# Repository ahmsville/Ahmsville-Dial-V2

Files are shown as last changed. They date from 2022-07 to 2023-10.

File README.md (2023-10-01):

# This Repository contains everything you need to build or customize your very own Ahmsville Dial.

## BUILD INSTRUCTIONS
 - https://www.ahmsvillelabs.io/ahmsvilledialbuild

# Ahmsville-Dial-V2
Main arduino library for the Ahmsville Dial V2.

Other Required Arduino Libraries:

Magnetic Rotary Encoder - https://github.com/ahmsville/Magnetic_rotary_encoding

Capacitive touch - https://github.com/PaulStoffregen/CapacitiveSensor

FastLED - https://github.com/FastLED/FastLED

RF24 - https://github.com/nRF24/RF24

Companion App - https://github.com/ahmsville/Ahmsville-Dial-App

**3D Printing Files** - https://gum.co/bkgfu

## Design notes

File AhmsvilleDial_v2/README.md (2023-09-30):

# Ahmsville-Dial-V2
Main arduino library for the Ahmsville Dial V2.

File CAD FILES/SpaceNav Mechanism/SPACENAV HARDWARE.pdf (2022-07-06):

Part name | Description | Option to Buy | Required Qty Link
10x5x1 magnets | Block Neodymium Magnet | 10x5x1mm | 4 | link (https://www.aliexpress.com/item/1005001409808794.html)
extension spring D3,L10,WT0.3 | 304 Stainless Dual Hook Small Expansion Tension Spring Hardware Accessories Wire Diameter 0.3mm Outer Diameter 3mm | 0.3 x 3 x 10mm | 4 | link (https://www.aliexpress.com/item/1005003468116909.html?scm_id=1007.40050.281175.0&scm-url=1007.40050.281175.0)
compression spring D14,L10,WT1.2 | Compression Spring 304 Stainless Steel Non-corrosive Tension Spring Wire Dia 1.2mm Outer Dia 14mm | 10mm length | 1 | link (https://www.aliexpress.com/item/1005003770155583.html)
Brass rivet M2X5mm HT1.2 | Brass Solid Rivets GB109 M2*L Flat Head Copper Rivets Solid Brass Rivet 2mm Diameter | M2 x 5mm | 4 | link (https://www.aliexpress.com/item/32971512695.html?spm=a2g0s.9042311.0.0.27424c4d3lAx2T)
M1.4 x 6mm Self tapping Screw | | M1.4x6mm | 8 | link (https://www.aliexpress.com/item/4000982209705.html?scm_id=1007.14452.226710.0&scm-url=1007.14452.226710.0)
M1.4 x 4mm Self tapping Screw | | M1.4x4mm | 4 | link (https://www.aliexpress.com/item/4000982209705.html?scm_id=1007.14452.226710.0&scm-url=1007.14452.226710.0)

## SPACENAV HARDWARE

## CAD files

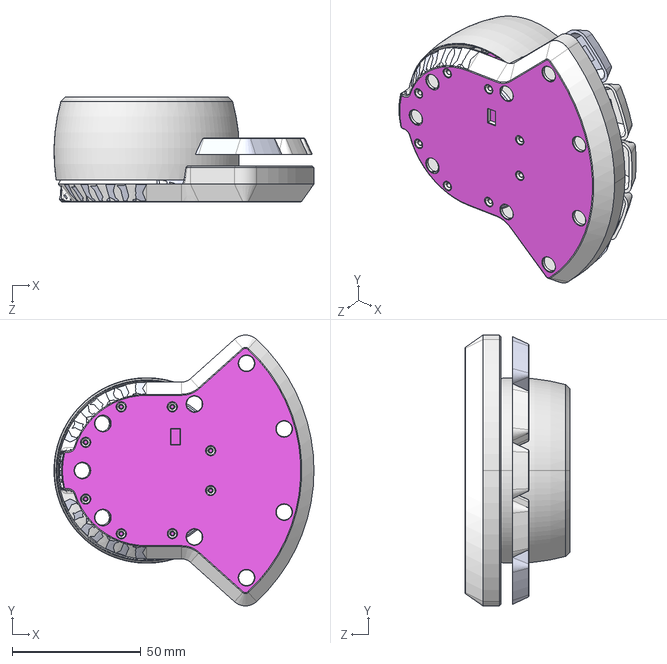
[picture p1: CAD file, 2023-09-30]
CAD FILES/DIAL/Ahmsville Dial - Base and Macro key Edition REV3.STEP
101.1 x 105.4 x 40.9 mm

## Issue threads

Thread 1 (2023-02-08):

Issue with 3D files

marekvse, 2023-02-08:
Hi Ahmed,
I have bought the full kit for Absolute variant from you, wanting to print my own colors. I first printed the case for the USB receiver, but it is obviously wrong. I have purchased the 3D files several weeks before purchasing the kit so the latest 3D files may have changed, but I don't want to purchase the same thing again just to find out if there is another version of the receiver case. In the version of 3D files I have there is v 1 and v1.1 of these.
Is there a newer version? Could you send it to me please? Just for the receiver would be enough, unless something else changed, too.

And I have an additional question if you don't mind...

In the purchased 3D files there are gcode files to print the multi-color parts, but they are (I think obviously, though I'm not a 3D printing expert), not going to work for all 3D printers. I have Creality Ender 3 S1 Plus, which seems to be using a different flavour of GCode.  Would you have some instructions on how to prepare the gcode files from your STLs that are separate for the logo and the rest of the top button for example?

Thanks,
Marek

ahmsville, 2023-02-08:
Hi marek,

Please note that the 3d files are free to download as many times as you like, gumroad only gives you the option to donate to the creator, all you need to do is enter 0 as the price and you can download the latest versions of the 3d files.

the included gcode files are outdated now so only use them as a reference on how to achieve the 2 color print.

marekvse, 2023-02-08:
I see. Thanks for that! :) I downloaded the USB receiver files and sure enough the 1.2 version looks like that should fit the rest I have from you :).

Thank you for a very nice design, too. I have not put it together yet as I'm currently printing the parts, but it does look very well designed. I'm looking forward to experiencing it operate.

I still have no idea how to make any slicer to go over the 3 layers of the logo to avoid them when printing the rest of the knob. I only had partial success in printing it. It's got some holes where the logo parts were pushed out of position. If I printed just the first layer of the logo it would be fine, but would it be strong enough...?

ahmsville, 2023-02-09:
you need at least two layers for the Surface, I could slice the parts for you if you'll like, I use a sapphire plus direct drive 0.6mm nozzle printer, not too far from what you have, so if you can tell me some settings specific to your printer, I can generate a useable gcode for you.

marekvse, 2023-02-09:
That would be great!! :)
I have prepared 1 and 2 layer logo files to try after everything else is printed, but my problem is that I can't seem to be able to make the printing head go up between the places where it prints to not bump into the others. Also, without that and 3 layers the height sensor (BLTouch) is already bumping into the printed layers as well, even though it was still able (just) to stumble over them.
So if you have a facility that makes the Z jumps possible or have some other clever technique I'd be very very happy if you could prepare the gcode for me. Much appreciated!

So, I'm not sure what you may need for the specific settings exactly, but here is what I assume you may need. If anything is missing please let me know:

**Printer settings:**
width: 300mm
depth: 300mm
rectangular
G-code flavor: Marlin

**Printhead settings:**
X min: -26mm
Y min: -32mm
X max: 32 mm
Y max: 34mm
Gantry height: 25mm
Apply extruder offsets to GCode: Yes

I have 0.4mm nozzle on it.

**Start G-code:**
```
; Ender 3 S1 Start G-code
G92 E0 ; Reset Extruder
G28 ; Home all axes
G1 Z10.0 F3000 ; Move Z Axis up little to prevent scratching of Heat Bed
G1 X0 Y0

M104 S{material_print_temperature_layer_0}
M190 S{material_bed_temperature_layer_0}
M109 S{material_print_temperature_layer_0}

G1 X0.1 Y20 Z0.3 F5000.0 ; Move to start position
G1 X0.1 Y200.0 Z0.3 F1500.0 E15 ; Draw the first line
G1 X0.4 Y200.0 Z0.3 F5000.0 ; Move to side a little
G1 X0.4 Y20 Z0.3 F1500.0 E30 ; Draw the second line
G92 E0 ; Reset Extruder
G1 Z2.0 F3000 ; Move Z Axis up little to prevent scratching of Heat Bed
G1 X5 Y20 Z0.3 F5000.0 ; Move over to prevent blob squish
```

**End G-code:**
```
G91 ;Relative positioning
G1 E-2 F2700 ;Retract a bit
G1 E-2 Z0.2 F2400 ;Retract and raise Z
G1 X5 Y5 F3000 ;Wipe out
G1 Z10 ;Raise Z more
G90 ;Absolute positioning

G1 X0 Y{machine_depth} ;Present print
M106 S0 ;Turn-off fan
M104 S0 ;Turn-off hotend
M140 S0 ;Turn-off bed

M84 X Y E ;Disable all steppers but Z
```

ahmsville, 2023-02-09:
the logo printing is done with Z hop, see the gcodes attached, print knob 1_1 first (logo), then print knob 1_2 after (knob), you can also preview the files before printing.
[KNOB 1 GCODE.zip](https://github.com/ahmsville/Ahmsville-Dial-V2/files/10691714/KNOB.1.GCODE.zip)

marekvse, 2023-02-09:
Excellent, thank you so very much.

RE Z hop: Yes, I discovered that when looking for a solution, but it did not seem to work. Maybe the printer does not recognize that G-code...? I'll sure find out when I try the one from you.

marekvse, 2023-02-09:
Which MECH HOLDER should one use: KEYLESS or the keyed one? The last piece to print (except reprinting of KNOB 1.)

By the way, how do you make the keycaps fit?
For others if that helps, I first tried a fine cutting instrument for a little bit before I tried directed hot air (using a soldering station) to heat the cross up a bit and then pressed it into the switch. It becomes a bit lose for a while but when it cools down again the fit is almost perfect (could be a tiny bit tighter, but its perfectly fine it seems, at least for something like this; I'm not sure I'd use this technique for a full keyboard, but maybe even that would work).

ahmsville, 2023-02-09:
I don't have to do any post processing with the keys, the secret is to use the avoid traveling through holes settings, also print at the lower temperature range of the filament, you are also printing the keyed spacenav holder.

marekvse, 2023-02-12:
I see.

Good o know if I want to change the color of the keys and thus print them again :).

Just to let you know that the G-code you made for me, unfortunately, did not work due to two problems. First, when it printed the logo it parked itself and did not finish the printing so that I could not select the second file to print. The second problem was something I should have let you know before, which is that my printer uses the BLTouch sensor at the beginning of every print and so I was doing my tries after I offset the printing position of the two files by 80mm on both x and y axis so that the center stays free for the BLTouch sensor step. Oh, actually the third problem was that it was (I think) printing the skirt and the retracted BLTouch tip was struggling to get across the already printed parts.

So in the end I tried by myself again, trying to print just 2 layers of the logo. That kind of worked, except that it dislodged in two of the four incomplete rings (I'm obviously printing the older design of the logo - just because I already had the gcode ready for it) and I then kind of fixed that with a 3D printing pen, filling manually the resulting inside ridges and thus also re-fixing the top to be all connected.
Thank you for the gcode files nevertheless!

Now I have two (probably last) questions if I may:

1) Will the capacitive touch work even after I made the inside top of the top knob slightly uneven after working with the hand-held 3D pen inside there? Is it designed so that it aligns perfectly with the inside top or is there a bit of space between the plastic and the capacitive sensor?

2) Does the dial work without having the battery installed?
  (I thought I don't need the wireless connection so I did not order the battery originally and it was only now that I realized that there is a possibility that the device will actually not work without it... So will it or will it not?)

Thanks,

Marek

ahmsville, 2023-02-14:
Hi Merek,

The capacitive touch will work regardless of the top surface's smoothness, the dial will also work without a lipo battery, to bypass the lipo charging circuit you can desolder the x4 pads and connect the pads beside it, doing this will provide the dial with stable power in the absence of a lipo. see attached picture.
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

marekvse, 2023-02-15:
Excellent. Thank you Ahmed for all your support. I still have not had the time yet to finish assembling the device but I can't wait to see it working.

ahmsville, 2023-02-15:
I am happy to help.

marekvse, 2023-03-11:
Hello Ahmed, sorry to bother you again. I have just finally found time to put all the magnets in and finish the assembly. In the meantime, the battery actually arrived so I connected the battery and thus powered the device for the first time. It seems to be running, the lights work, the capacitative touch works for Pause / Play youtube videos, but the thing I was most excited about to use it for of course was Fusion 360. I've followed the complete installation procedure and pressing the 5th button shows the popup identifying Fusion 360 correctly:
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
However, I'm getting no response whatsoever in Fusion from the dial so I cannot be sure that the dial actually works apart from the 5th button and the capacitative touch.
I have also confirmed that the Ahmsville Fusion 360 addin is installed and running in Fusion 360.

One thing I have not done yet is to push the knobs onto the bearings as it looks like it would be very hard, if not impossible, to get them off again after that and until I confirm that it all works I don't want to prevent myself from accessing the wiring.

Could you provide any guidance?

marekvse, 2023-03-14:
Finally, I want to say thank you! :) I've finally managed to find the time to put all the magnets in, in the meantime, even the battery arrived and yesterday I finally managed to connect the device for the first time. Above, now hidden comment, I first wrote for help as only the capacitive touch seemed to work and no functions in Fusion 360, but then it finally, somehow, managed to start working. I found that I need a longer cable to use the device where I need it and I need to finish building my smaller keyboard to fit it all to the space I have, but the important thing is here that it works.

One question in the end... If I even need to disassemble it, have you tested whether the knobs can be taken off the bearings safely without breaking anything. I'd be worried if I ever needed to do that.

Oh, actually one more comment: The bottom knob rotates reasonably freely - that is if I give it a faster push it keeps rotating for about a second after the force ends (I expected better, but nevertheless it is very easy to rotate), but the top one has more resistance and cannot be easily rotated with just one finger without tilting the device. Is that by design to have to rotate it with a two-finger grip?

Closed 2023-02-08.

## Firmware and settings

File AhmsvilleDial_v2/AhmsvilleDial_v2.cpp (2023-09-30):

#include "AhmsvilleDial_v2.h"



/*


....By Ahmed Oyenuga (Ahmsville 2019).
*/


//MagRotaryEncoder AhmsvilleDial_Knob = MagRotaryEncoder(A1, A0, 38, 27); // create new encoding instance and specify the arduino pins connected to the hall effect sensors
MagRotaryEncoder AhmsvilleDial_Knob = MagRotaryEncoder(A1, A0);
#if DIAL_VERSION == 3 || DIAL_VERSION == 4
//MagRotaryEncoder AhmsvilleDial_Knob2 = MagRotaryEncoder(A2, A3, 42, 13);
MagRotaryEncoder AhmsvilleDial_Knob2 = MagRotaryEncoder(A2, A3);

#endif


volatile int activesensorInterrupt = 1, knob2activesensorInterrupt = 1;


void mainISR1() {

	AhmsvilleDial_Knob.singleSensor_INT(1);
}
#if DIAL_VERSION == 3 || DIAL_VERSION == 4
void mainISR2() {

	AhmsvilleDial_Knob2.singleSensor_INT(1);
}

#endif
void setknobinterrupt() {
	pinMode(AhmsvilleDial_Knob.get_sensorINTpin(1), INPUT);
	attachInterrupt(digitalPinToInterrupt(AhmsvilleDial_Knob.get_sensorINTpin(1)), mainISR1, RISING);

	pinMode(AhmsvilleDial_Knob.get_sensorINTpin(2), INPUT);
	attachInterrupt(digitalPinToInterrupt(AhmsvilleDial_Knob.get_sensorINTpin(2)), mainISR1, RISING);

#if DIAL_VERSION == 3 || DIAL_VERSION == 4
	pinMode(AhmsvilleDial_Knob2.get_sensorINTpin(1), INPUT);
	attachInterrupt(digitalPinToInterrupt(AhmsvilleDial_Knob2.get_sensorINTpin(1)), mainISR2, RISING);

	pinMode(AhmsvilleDial_Knob2.get_sensorINTpin(2), INPUT);
	attachInterrupt(digitalPinToInterrupt(AhmsvilleDial_Knob2.get_sensorINTpin(2)), mainISR2, RISING);
#endif // DIAL_VERSION == 3 || DIAL_VERSION == 4


}


AhmsvilleDial::AhmsvilleDial() {
	pinMode(30, OUTPUT);
	digitalWrite(30, LOW);
	delay(500);
}

void AhmsvilleDial::resetdial() {

	//AhmsvilleDial_Touch = AdvCapTouch();
	//AhmsvilleDial_Knob = MagRotaryEncoder(A1, A0, 38, 27);
#if DIAL_VERSION == 3 || DIAL_VERSION == 4
	//AhmsvilleDial_Knob2 = MagRotaryEncoder(A2, A3, 42, 13);
	AhmsvilleDial_Spacenav.softreset();
	if(gyro_x_y_radius[2] > 0.0){
          AhmsvilleDial_Spacenav.set_tiltBoundaryRadii(100, gyro_x_y_radius[2]+0.5);
    }
    if(plane_x_y_radius[2] > 0.0){
        AhmsvilleDial_Spacenav.set_slideBoundaryRadii(100, plane_x_y_radius[2]+0.5);
    }
	/*AhmsvilleDial_Spacenav.set_XYSensorPins(A5, A4);
	AhmsvilleDial_Spacenav.set_adaptiveSpaceNavigation(true);
	AhmsvilleDial_Spacenav.set_slideBoundaryRadii(100, 0);
	AhmsvilleDial_Spacenav.set_tiltBoundaryRadii(100, 0);
	AhmsvilleDial_Spacenav.initialize_spaceNav();*/
#endif // DIAL_VERSION == 3 || DIAL_VERSION == 4

#if DIAL_VERSION == 2 || DIAL_VERSION == 4
	//AhmsvilleDial_Mkey = MacroKey();
#endif // DIAL_VERSION == 2 || DIAL_VERSION == 4

}
void AhmsvilleDial::initialize_ahmsvilleDial() {
	//setknobinterrupt();
	set_haptics(4, 60, 20, 5, 200); //int pin, int durationtouch, int durationknob, int durationspacenav, int strength

	analogReadResolution(12);
	setknobresolution(0, 1,false);


#if DIAL_VERSION == 3 || DIAL_VERSION == 4

	setknobresolution(0,2,false);

	AhmsvilleDial_Spacenav.set_XYSensorPins(A5, A4);
	AhmsvilleDial_Spacenav.set_adaptiveSpaceNavigation(false);
	AhmsvilleDial_Spacenav.set_slideBoundaryRadii(100, 0);
	AhmsvilleDial_Spacenav.set_tiltBoundaryRadii(100, 0);

	AhmsvilleDial_Spacenav.initialize_spaceNav();
#endif // DIAL_VERSION == 3 || DIAL_VERSION == 4

	AhmsvilleDial_Touch.set_capTouchPins(9, 8, 0, 0, 0);   //sets the arduino pins used for the capacitive touch (sendpin, pad1, pad2, pad3, pad4)
	//AhmsvilleDial_Touch.set_inputTypeThresholds(300, 320, 800, 250);  //sets the thresholds for the four input types  (singletap, shortpress, longpress, doubletapspeed)
	//AhmsvilleDial_Touch.set_adaptiveSensitivity(1, 0.4, true);  //set touch sensitivity to auto
	AhmsvilleDial_Touch.initialize_capTouch(1);

#if DIAL_VERSION == 2 || DIAL_VERSION == 4
	AhmsvilleDial_Mkey.initialize_macroKey();
#endif // DIAL_VERSION == 2 || DIAL_VERSION == 4



	Keyboard.begin();
	Mouse.begin();
}

void AhmsvilleDial::initialize_ahmsvilleDialCustom(int touchpin) {

}

void AhmsvilleDial::set_inputTypeThresholds(int st, int sp, int lp, int dt) {
	AhmsvilleDial_Touch.set_inputTypeThresholds(st, sp, lp, dt);
}

void AhmsvilleDial::set_haptics(int pin, int durationtouch, int durationknob, int durationspacenav, int strength) {
	AhmsvilleDial_Touch.set_haptics(pin, durationtouch, 255);
	AhmsvilleDial_Knob.set_haptics(pin, durationknob, strength);
	haptics_pin = pin;

#if DIAL_VERSION == 3 || DIAL_VERSION == 4
	AhmsvilleDial_Knob2.set_haptics(pin, durationknob, 255);
	AhmsvilleDial_Spacenav.set_haptics(pin, durationspacenav, 75);
#endif // DIAL_VERSION == 3 || DIAL_VERSION == 4

}

int AhmsvilleDial::capTouch(int pad) {

	int touch = AhmsvilleDial_Touch.detect_touchFromNoise(pad);
	return touch;


}

void AhmsvilleDial::capTouchInterrupt() {

	AhmsvilleDial_Touch.read_valueFromNoise_interrupt();

}

int AhmsvilleDial::capTouch() {
	int touch = AhmsvilleDial_Touch.detect_touchFromNoise(0);
	return touch;
}

int AhmsvilleDial::capTouch_single() {
	int touch = AhmsvilleDial_Touch.detect_touchFromNoise_single(0);
	return touch;
}

int AhmsvilleDial::capTouch_single(int pad) {
	int touch = AhmsvilleDial_Touch.detect_touchFromNoise_single(pad);
	return touch;
}



int AhmsvilleDial::knob() {
	knobcount = 0;
	if (knob1setres > 0)
	{
		knobcount = int(AhmsvilleDial_Knob.detect_rotationHR());
	}
	else {
		knobcount = AhmsvilleDial_Knob.detect_rotation();
	}
	if (knobcount != 0) {
		AhmsvilleDial_Knob.setsleep(false);
	}
	//SerialUSB.println(knobcount);
	return knobcount;
}

float AhmsvilleDial::knobAbsolute() {
	float knobfloatcount = 0;
	if (knob1setres == 0) {
		knobfloatcount = float(AhmsvilleDial_Knob.detect_rotation());
	}
	else {
		knobfloatcount = AhmsvilleDial_Knob.detect_rotationHR();
	}

	if (knobfloatcount != 0) {
		AhmsvilleDial_Knob.setsleep(false);
	}

	return knobfloatcount;
}


void AhmsvilleDial::normalize() {

	//AhmsvilleDial_Touch.update_basevalueFromNoise(0);
	//AhmsvilleDial_Knob.recaliberate_startPosition();
	eventnotification(0);

#if DIAL_VERSION == 2 || DIAL_VERSION == 4
	//AhmsvilleDial_Mkey.reset_macroKey();
#endif // 0	

#if DIAL_VERSION == 3 || DIAL_VERSION == 4
	//AhmsvilleDial_Knob2.recaliberate_startPosition();

	AhmsvilleDial_Spacenav.reset_spaceNav();
#endif // DIAL_VERSION == 3 || DIAL_VERSION == 4
}
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

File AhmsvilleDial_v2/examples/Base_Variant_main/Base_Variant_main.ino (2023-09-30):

#include <AhmsvilleDial_v2.h>
#include <FastLED.h>
#include <SPI.h>
#include "RF24.h"

#define maxconfignum 1

AhmsvilleDial ahmsville_dial; //create a new ahmsville dial instance
RF24 radio(6, 7);                          // Set up nRF24L01 radio on SPI bus plus pins 7 & 8(CE,CSN)



#define substrlen 12
#define serialdatalength 30



byte addresses[][6] = { "1Node", "2Node" };



#define DATA_PIN    3
#define LED_TYPE    WS2812B
#define COLOR_ORDER GRB
#define NUM_LEDS   8
#define MK_LEDS   0


CRGB leds[NUM_LEDS];

#define BRIGHTNESS         96

CRGBPalette16 currentPalette;
TBlendType    currentBlending;

uint8_t gHue = 0; // rotating "base color"


#define MOUSEMOVE '/'
#define MOUSEMOVE_UP 'U'
#define MOUSEMOVE_DOWN 'D'
#define MOUSEMOVE_LEFT 'L'
#define MOUSEMOVE_RIGHT 'R'
char KEY_SPACEBAR = 32;
char nullchar = 128;

#define ALLColors CRGB::Teal
#define NotSet CRGB::Snow
#define solid 0
#define ColorWheel 1
#define Breath 2
#define Cardio 3
#define Rainbow 4
#define SpacklingRainbow 5
#define Confetti 6
#define Jungle 7


struct {
  uint8_t brightness = BRIGHTNESS;
  uint8_t gHue = 0;
  long gHuetiming = 0;
  long timing = 0;
  uint8_t state = 0;
} Dleds[NUM_LEDS];


struct {
  int beatcount = 0;
  int breathfader = 1;
} A_variables[NUM_LEDS];


int blackpoint = 240;


// the following lines define the index of loaded config to be used in the Dial App
#define knob1CW "the app is in charge of ths000"
#define knob1CCW "the app is in charge of ths001"
#define knob2CW "the app is in charge of ths002"
#define knob2CCW "the app is in charge of ths003"
#define captouch_singletap_con1 "the app is in charge of ths004"
#define captouch_singletap_con2 "the app is in charge of ths005"
#define captouch_doubletap_con1 "the app is in charge of ths006"
#define captouch_doubletap_con2 "the app is in charge of ths007"
#define captouch_shortpress "the app is in charge of ths008"
#define captouch_longpress "the app is in charge of ths009"
#define MK1tap_con1 "the app is in charge of ths010"
#define MK1tap_con2 "the app is in charge of ths011"
#define MK1hold "the app is in charge of ths012"
#define MK2tap_con1 "the app is in charge of ths013"
#define MK2tap_con2 "the app is in charge of ths014"
#define MK2hold "the app is in charge of ths015"
#define MK3tap_con1 "the app is in charge of ths016"
#define MK3tap_con2 "the app is in charge of ths017"
#define MK3hold "the app is in charge of ths018"
#define MK4tap_con1 "the app is in charge of ths019"
#define MK4tap_con2 "the app is in charge of ths020"
#define MK4hold "the app is in charge of ths021"
#define MK5tap_con1 "the app is in charge of ths022"
#define MK5tap_con2 "the app is in charge of ths023"
#define MK5hold "the app is in charge of ths024"
#define SPnav_tiltup "the app is in charge of ths025"
#define SPnav_tiltdown "the app is in charge of ths026"
#define SPnav_tiltright "the app is in charge of ths027"
#define SPnav_tiltleft "the app is in charge of ths028"
#define SPnav_slideup "the app is in charge of ths029"
#define SPnav_slidedown "the app is in charge of ths030"
#define SPnav_slideright "the app is in charge of ths031"
#define SPnav_slideleft "the app is in charge of ths032"


#define typekeystroke 1
#define typemousectrl 2
#define typekeystring 3
#define typespacenavraw 4


int dialcontrollmode = 0;
long popupopentime = 0, popupclosetime = 7000;



struct {
  String appname;  //application or configuration name
  int ID;  //application or configuration ID
  long appcolor;  //LED color assigned to the application or configuration
  byte appanimation;
  int knob1_res;  //knob1 resolution
  bool useapp_knob1_CW;
  char knob1_CW[3];  //knob1 clockwise shortcuts keys (application specific)
  bool useapp_knob1_CCW;
  char knob1_CCW[3];  //knob1 counter-clockwise shortcuts keys (application specific)
 /* int knob2_res;  //knob2 resolution
  bool useapp_knob2_CW;
  char knob2_CW[3];  //knob2 clockwise shortcuts keys (application specific)
  bool useapp_knob2_CCW;
  char knob2_CCW[3]; //knob2 counter-clockwise shortcuts keys (application specific)*/
  bool captouch_dualtapfunc[2];
  bool useapp_captouch_singletap;
  char singletap[3];  //capacitive touch singletap shortcuts keys (application specific)
  bool useapp_captouch_singletap2;
  char singletap2[3];
  bool useapp_captouch_doubletap;
  char doubletap[3];  //capacitive touch doubletap shortcuts keys (application specific)
  bool useapp_captouch_doubletap2;
  char doubletap2[3];
  bool useapp_captouch_shortpress;
  char shortpress[3];  //capacitive touch shortpress shortcuts keys (application specific)
  bool useapp_captouch_longpress;
  char longpress[3];  //capacitive touch longpress shortcuts keys (application specific)
  /*bool MK_dualtapfunc[5];
  bool MK_tapfunc[5];  //configures each macro key tap to function as a shortcut or to print out a predefined text
  bool MK_holdfunc[5];  //configures each macro hold key to function as a shortcut or to print out a predefined text
  long MK_colors[5];  //sets the individual colors of each macro key
  byte MK_animation[5];
  bool useapp_MK1_tap;
  char MK1_tap[3];  //macro key 1 tap shortcuts keys (application specific)
  bool useapp_MK1_tap2;
  char MK1_tap2[3];
  String MK1_taptext;  //macro key 1 tap predefined text
  bool useapp_MK1_hold;
  char MK1_hold[3];  //macro key 1 hold shortcuts keys (application specific)
  String MK1_holdtext;  //macro key 1 hold predefined text
  bool useapp_MK2_tap;
  char MK2_tap[3];  //macro key 2 tap shortcuts keys (application specific)
  bool useapp_MK2_tap2;
  char MK2_tap2[3];
  String MK2_taptext;  //macro key 2 tap predefined text
  bool useapp_MK2_hold;
  char MK2_hold[3];  //macro key 2 hold shortcuts keys (application specific)
  String MK2_holdtext;  //macro key 2 hold predefined text
  bool useapp_MK3_tap;
  char MK3_tap[3];  //macro key 3 tap shortcuts keys (application specific)
  bool useapp_MK3_tap2;
  char MK3_tap2[3];
  String MK3_taptext;  //macro key 3 tap predefined text
  bool useapp_MK3_hold;
  char MK3_hold[3];  //macro key 3 hold shortcuts keys (application specific)
  String MK3_holdtext;  //macro key 3 hold predefined text
  bool useapp_MK4_tap;
  char MK4_tap[3];  //macro key 4 tap shortcuts keys (application specific)
  bool useapp_MK4_tap2;
  char MK4_tap2[3];
  String MK4_taptext;  //macro key 4 tap predefined text
  bool useapp_MK4_hold;
  char MK4_hold[3];  //macro key 4 hold shortcuts keys (application specific)
  String MK4_holdtext;  //macro key 4 hold predefined text
  bool useapp_MK5_tap;
  char MK5_tap[3];  //macro key 5 tap shortcuts keys (application specific)
  bool useapp_MK5_tap2;
  char MK5_tap2[3];
  String MK5_taptext;  //macro key 5 tap predefined text
  bool useapp_MK5_hold;
  char MK5_hold[3];  //macro key 5 hold shortcuts keys (application specific)
  String MK5_holdtext;  //macro key 5 hold predefined text
  int spacenav_func;  //integer value for setting which CAD application the dial's space navigator works with.
  bool spacenav_continuousmode[2];
  bool useapp_spacenav_tiltup;
  char spacenav_tiltup[3];  //space navigator tilt up shortcut keys (application specific)
  bool useapp_spacenav_tiltdown;
  char spacenav_tiltdown[3];  //space navigator tilt down shortcut keys (application specific)
  bool useapp_spacenav_tiltright;
  char spacenav_tiltright[3];  //space navigator tilt right shortcut keys (application specific)
  bool useapp_spacenav_tiltleft;
  char spacenav_tiltleft[3];  //space navigator tilt left shortcut keys (application specific)
  bool useapp_spacenav_slideup;
  char spacenav_slideup[3];  //space navigator slide up shortcut keys (application specific)
  bool useapp_spacenav_slidedown;
  char spacenav_slidedown[3];  //space navigator slide down shortcut keys (application specific)
  bool useapp_spacenav_slideright;
  char spacenav_slideright[3];  //space navigator slide right shortcut keys (application specific)
  bool useapp_spacenav_slideleft;
  char spacenav_slideleft[3];  //space navigator slide left shortcut keys (application specific)*/

} appconfig[maxconfignum];

int activeappid = 0, prevactiveappid = 0, count1 = 0, count2 = 0, touch = 0;


int generalKeyPressInterval = 0;
int normalKeyInterval = 150;
bool captouchdualtapmodes[2] = { 0, 0 };
bool MK1dualtapmodes = 0;
bool MK2dualtapmodes = 0;
bool MK3dualtapmodes = 0;
bool MK4dualtapmodes = 0;
bool MK5dualtapmodes = 0;
int samplekey = 0;

byte inByte;         // incoming SerialUSB byte
String inString = "";



struct PacketStruct {
  bool updateConfigID = false;
  bool spacenavRawAvailable = false;
  bool inapp = false;
  byte inappcommandID = 0;
  bool keyormouse = false; //0 = keyboard, 1 = mouse
  bool is_string = false; //0 = simple keystroke, 1 = prepare to receive long string
  char keystroke;
  char mousecontrol;
  byte mouseX;
  byte mouseY;
  bool ctrlrelease = false;
  byte dialID = 1;
} dialPacket;

struct stringPrintingPacket {
  char stringdata[substrlen];
  bool endofstring = false;
} stringtoprint;

struct spacenavRawPacket {
  float SNG_x;
  float SNG_y;
  float SNG_rad;
  float SNP_x;
  float SNP_y;
  float SNP_rad;
} spacenavRaw;



struct W_adapterPacket {
  byte appID = 0; //from PC via Serial, is also ack payload
  bool active = true; //tells dial wireless adapter is available
} WAPacket; //from wireless adapter



long configidupdate = 0;
long timedIDupdate = 0;
long timedReconnect = 0;

int sleeptime = 30000;
volatile long lastinputtime = 0;

#define connecting 0
#define wired 1
#define wireless 2

int connectState = 0;

long mousereleaseinterval = 200;
long mousecontroltime = 0;
int mousemoveMul = 1;

void setup() {
  delay(5000);
  SerialUSB.begin(115200);
  //while(!SerialUSB){ SerialUSB.begin(115200);}
  setupCommunication();
  // tell FastLED about the LED strip configuration
  FastLED.addLeds<LED_TYPE, DATA_PIN, COLOR_ORDER>(leds, NUM_LEDS).setCorrection(TypicalLEDStrip);
  // set master brightness control
  FastLED.setBrightness(BRIGHTNESS);
  currentPalette = RainbowColors_p;
  currentBlending = LINEARBLEND;


  ahmsville_dial.initialize_ahmsvilleDial();
  Load_Configurations();
  updateknobresolution();
}

void loop() {

  //long fftime = millis();
  //SerialUSB.println(fftime);
  //SerialUSB.println(lastinputtime);


  sleepMode();
  if (dialcontrollmode == 0) { //normal op
      getinputs(); //get and process input
  }
  else if (dialcontrollmode == 1) { //popupmode
      getinputs_popup();
  }
  connecttoPC();
  updatedialLeds();

  mouserelease();

  // SerialUSB.println(activeappid);
  // SerialUSB.println((millis() - fftime));

}

void sleepMode() {
  if ((millis() - lastinputtime) > sleeptime || touch == 5) { //no interraction with dial for a set time
    if (connectState == wireless || touch == 5) { //wireless mode
      DeactivateDial(true);
      ahmsville_dial.setsleep(true);
      while (ahmsville_dial.readsleep()) { //turn dial to wake
        // SerialUSB.println("Sleeping"); //sleepmode
        ahmsville_dial.knob();
      }
      // DeactivateDial();
      lastinputtime = millis();
      //digitalWrite(30, HIGH); //turn off Radio and Motion tracker
      //delay(500);
      //setupCommunication();
    }
  }
}


void setmousemoveMul(float value) {
  mousemoveMul = (((100.00 / 50.00) * value) / 100.00) * 20.00; //  (((100%/maxradii)*value)/100%) * maxallowedmovemul
}

void getinputs_popup() {
    count1 = ahmsville_dial.knob();  //detecting knob rotations (returns a signed integer in relation to the direction of the rotation)
    touch = ahmsville_dial.capTouch();  //detecting capacitive touch (returns integer 1 - 4 or 0 when no touch is detected)
    while (touch == -1) {
        touch = ahmsville_dial.capTouch();
    }
    /*****************************Encoder*************************/
    if (count1 > 0) {
        processDialInput(0, '0', false, knob1CW, 0, true);
        popupopentime = millis();
    }
    else if (count1 < 0) {
        processDialInput(0, '0', false, knob1CCW, 0, true);
        popupopentime = millis();
    }
    else {
        // processDialInput(0, '0', false, "the app is in charge of ths222", 0, true);
    }
    /*****************************Captouch*************************/
    if (touch == 1) {
        processDialInput(0, '0', false, "the app is in charge of ths222", 0, true);
        popupopentime = millis();
    }
    else if (touch == 2) {
        processDialInput(0, '0', false, captouch_doubletap_con1, 0, true);
        popupopentime = millis();
    }

    if ((millis() - popupopentime) > popupclosetime) { //reset to mormal
        dialcontrollmode = 0;
        processDialInput(0, '0', false, "the app is in charge of ths222", 0, true);
    }

    ahmsville_dial.normalize();
}

void getinputs() {
 touch = ahmsville_dial.capTouch();  //detecting capacitive touch (returns integer 1 - 4 or 0 when no touch is detected)
   while(touch == -1){
    touch = ahmsville_dial.capTouch(); 
   }
  count1 = ahmsville_dial.knob();  //detecting knob rotations (returns a signed integer in relation to the direction of the rotation)
  // SerialUSB.println(count1);
 
 	/****************************************************************CAPTOUCH******************************************************************/
	if (touch == 1) { //cap touch is singletap
		if (appconfig[activeappid].captouch_dualtapfunc[0] == true) { //if dual shortcut is enabled for macro key1
			if (captouchdualtapmodes[0] == 0) { //use macro key1 shortcut1 / check previously used shortcut combo...
				if (appconfig[activeappid].useapp_captouch_singletap == false) { //if dial is not set to use app for this dial input - talk to PC directly via keyboard and mouse
					for (int i = 0; i < 3; i++) { //loop through shortcut keys
						if (appconfig[activeappid].singletap[i] != nullchar) {
							if (shortcutcommandType(appconfig[activeappid].singletap[i]) == true) {
								if (appconfig[activeappid].singletap[i + 1] == nullchar || i == 2) { //is the last or only keystroke use keyboard.write
									processDialInput(typekeystroke, appconfig[activeappid].singletap[i], true, "", 0, false);
								}
								else {
									processDialInput(typekeystroke, appconfig[activeappid].singletap[i], false, "", 0, false);
									if (!isSpecialKey(appconfig[activeappid].singletap[i])) { //is not Special key release immediately
										processDialInput(0, '0', false, "", 1, false);
										if (i < 2 && appconfig[activeappid].singletap[i + 1] != nullchar) { //delay between normal key combinations
											delay(normalKeyInterval);
										}
									}
									//Keyboard.press(appconfig[activeappid].singletap[i]);
									delay(generalKeyPressInterval);
								}
							}
							else {
								processDialInput(typemousectrl, appconfig[activeappid].singletap[i], false, "", 0, false);
								//mouseControl(appconfig[activeappid].singletap[i]);
							}
						}
					}
					processDialInput(0, '0', false, "", 1, false);

				}
				else { //talk to app instead
					processDialInput(0, '0', false, captouch_singletap_con1, 0, true);
					// SerialUSB.print(captouch_singletap_con1);
				}
				captouchdualtapmodes[0] = !captouchdualtapmodes[0];  //invert for the next tap
			}
			else if (captouchdualtapmodes[0] == 1) {  //use macro key1 shortcut2
				if (appconfig[activeappid].useapp_captouch_singletap2 == false) { //if dial is not set to use app for this dial input - talk to PC directly via keyboard and mouse
					for (int i = 0; i < 3; i++) { //loop through shortcut keys
						if (appconfig[activeappid].singletap2[i] != nullchar) {
							if (shortcutcommandType(appconfig[activeappid].singletap2[i]) == true) {
								if (appconfig[activeappid].singletap2[i + 1] == nullchar || i == 2) { //is the last or only keystroke use keyboard.write
									processDialInput(typekeystroke, appconfig[activeappid].singletap2[i], true, "", 0, false);
								}
								else {
									processDialInput(typekeystroke, appconfig[activeappid].singletap2[i], false, "", 0, false);
									if (!isSpecialKey(appconfig[activeappid].singletap2[i])) { //is not Special key release immediately
										processDialInput(0, '0', false, "", 1, false);
										if (i < 2 && appconfig[activeappid].singletap2[i + 1] != nullchar) { //delay between normal key combinations
											delay(normalKeyInterval);
										}
									}
									//Keyboard.press(appconfig[activeappid].singletap[i]);
									delay(generalKeyPressInterval);
								}
							}
							else {
								processDialInput(typemousectrl, appconfig[activeappid].singletap2[i], false, "", 0, false);
								// mouseControl(appconfig[activeappid].singletap2[i]);
							}
						}
					}
					processDialInput(0, '0', false, "", 1, false);

				}
				else { //talk to app instead
					processDialInput(0, '0', false, captouch_singletap_con2, 0, true);
					//SerialUSB.print(captouch_singletap_con2);
				}
				captouchdualtapmodes[0] = !captouchdualtapmodes[0];  //invert for the next tap
			}
		}
		else {
			if (appconfig[activeappid].useapp_captouch_singletap == false) { //if dial is not set to use app for this dial input - talk to PC directly via keyboard and mouse
				for (int i = 0; i < 3; i++) { //loop through shortcut keys
					if (appconfig[activeappid].singletap[i] != nullchar) {
						if (shortcutcommandType(appconfig[activeappid].singletap[i]) == true) {
							if (appconfig[activeappid].singletap[i + 1] == nullchar || i == 2) { //is the last or only keystroke use keyboard.write
								processDialInput(typekeystroke, appconfig[activeappid].singletap[i], true, "", 0, false);
							}
							else {
								processDialInput(typekeystroke, appconfig[activeappid].singletap[i], false, "", 0, false);
								if (!isSpecialKey(appconfig[activeappid].singletap[i])) { //is not Special key release immediately
									processDialInput(0, '0', false, "", 1, false);
									if (i < 2 && appconfig[activeappid].singletap[i + 1] != nullchar) { //delay between normal key combinations
										delay(normalKeyInterval);
									}
								}
								//Keyboard.press(appconfig[activeappid].singletap[i]);
								delay(generalKeyPressInterval);
							}
						}
						else {
							processDialInput(typemousectrl, appconfig[activeappid].singletap[i], false, "", 0, false);
							//  mouseControl(appconfig[activeappid].singletap[i]);
						}
					}
				}
				processDialInput(0, '0', false, "", 1, false);

			}
			else { //talk to app instead
				processDialInput(0, '0', false, captouch_singletap_con1, 0, true);
				// SerialUSB.print(captouch_singletap_con1);
			}
		}
	}
	/*-----------------------------------------------------------------------------------*/
	else if (touch == 2) { //cap touch is doubletap
		if (appconfig[activeappid].captouch_dualtapfunc[1] == true) { //if dual shortcut is enabled for macro key1
			if (captouchdualtapmodes[1] == 0) { //use macro key1 shortcut1 / check previously used shortcut combo...
				if (appconfig[activeappid].useapp_captouch_doubletap == false) { //if dial is not set to use app for this dial input - talk to PC directly via keyboard and mouse
					for (int i = 0; i < 3; i++) { //loop through shortcut keys
						if (appconfig[activeappid].doubletap[i] != nullchar) {
							if (shortcutcommandType(appconfig[activeappid].doubletap[i]) == true) {
								if (appconfig[activeappid].doubletap[i + 1] == nullchar || i == 2) { //is the last or only keystroke use keyboard.write
									processDialInput(typekeystroke, appconfig[activeappid].doubletap[i], true, "", 0, false);
								}
								else {
									processDialInput(typekeystroke, appconfig[activeappid].doubletap[i], false, "", 0, false);
									if (!isSpecialKey(appconfig[activeappid].doubletap[i])) { //is not Special key release immediately
										processDialInput(0, '0', false, "", 1, false);
										if (i < 2 && appconfig[activeappid].doubletap[i + 1] != nullchar) { //delay between normal key combinations
											delay(normalKeyInterval);
										}
									}
									//Keyboard.press(appconfig[activeappid].doubletap[i]);
									delay(generalKeyPressInterval);
								}
							}
							else {
								processDialInput(typemousectrl, appconfig[activeappid].doubletap[i], false, "", 0, false);
								//mouseControl(appconfig[activeappid].doubletap[i]);
							}
						}
					}
					processDialInput(0, '0', false, "", 1, false);
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
